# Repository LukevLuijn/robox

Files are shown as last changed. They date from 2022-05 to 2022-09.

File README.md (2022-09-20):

# ROBOX

Everything you need to build your own ROBOX!

## Documentation

|#|Document|Description|
|:---:|:---|:---|
|DOC-00|[**Message protocol**](https://github.com/LukevLuijn/robox_docs/blob/b1542c1bec19ce677cf1c12f30072f8e4e05e07a/protocol/protocol_description.pdf)|Description about the used protocol for the communication between the firmware and software.|
|DOC-01|[**Bill of materials**](https://github.com/LukevLuijn/robox_docs/blob/b1542c1bec19ce677cf1c12f30072f8e4e05e07a/hardware/bill_of_materials/README.md)|Bill of materials.|
|DOC-02|[**Design documentation**](https://github.com/LukevLuijn/robox_docs)|Full design documentation, all written in dutch.|

## Additional control methods

|#|Method|Description|State|
|:---:|:---|:---|:---|
|MD-01|[**BKE-Control**](https://github.com/LukevLuijn/robox/tree/BKE-control)|Models and code implementation for the ability to play games of noughts and crosses against human players autonomously.|Finished|
|MD-02|**BLT-Control**|Additional control method for controlling the robot trough a bluetooth controller such as a Playstation 4 controller.|Not started|
|MD-03|**Keyboard-control**|Additional control method for controlling the robot trough a combination of keys on a standard keyboard.|Not started|
|MD-04|**Vision-control**|Models and code implementation to control the robot trough a webcam and various visual triggers such as hand gestures or shapes.|Not started|

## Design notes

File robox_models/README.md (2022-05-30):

# ROBOX Models

This directory contains all .stl files needed to print your own ROBOX.

## Robox assembly

|||
|:--:|:---:|
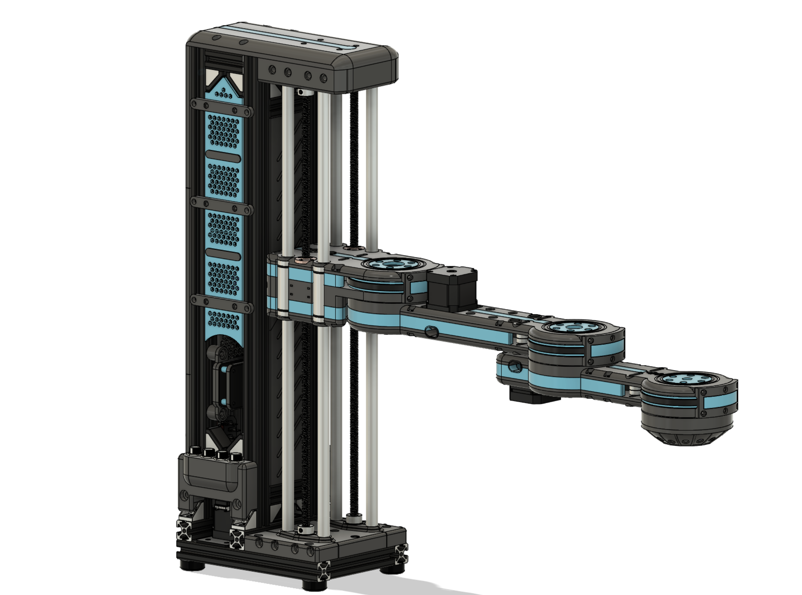
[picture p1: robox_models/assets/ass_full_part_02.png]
assembly01
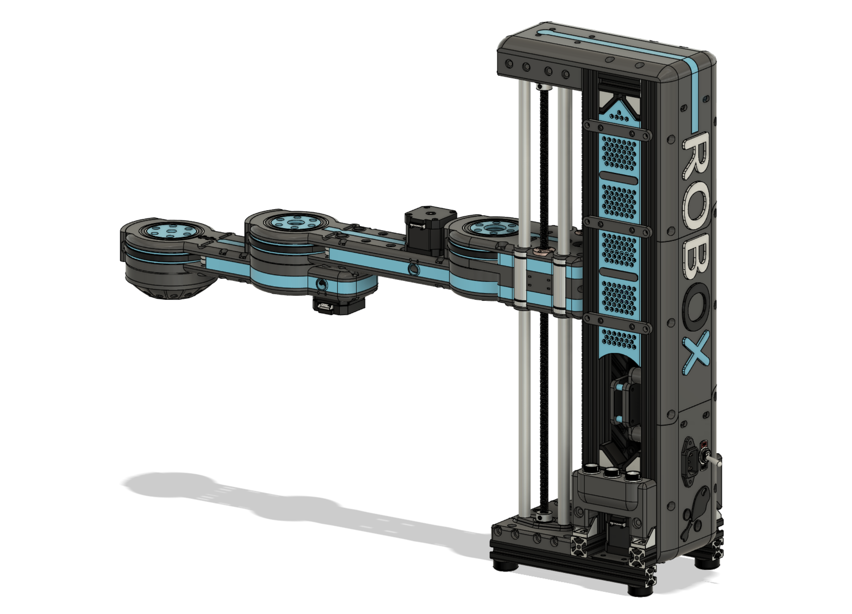
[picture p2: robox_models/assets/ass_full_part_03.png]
assembly02
|||
|**Image 1** - *Assembly front view*|**Image 2** - *Assembly back view*|

## Segments

|||
|:---:|:---:|
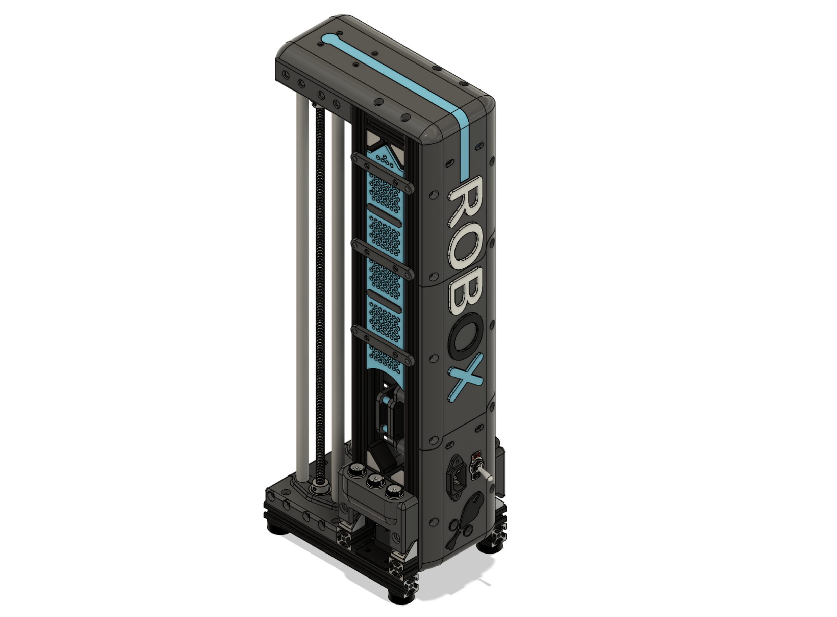
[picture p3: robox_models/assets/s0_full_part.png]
robox_segment_00
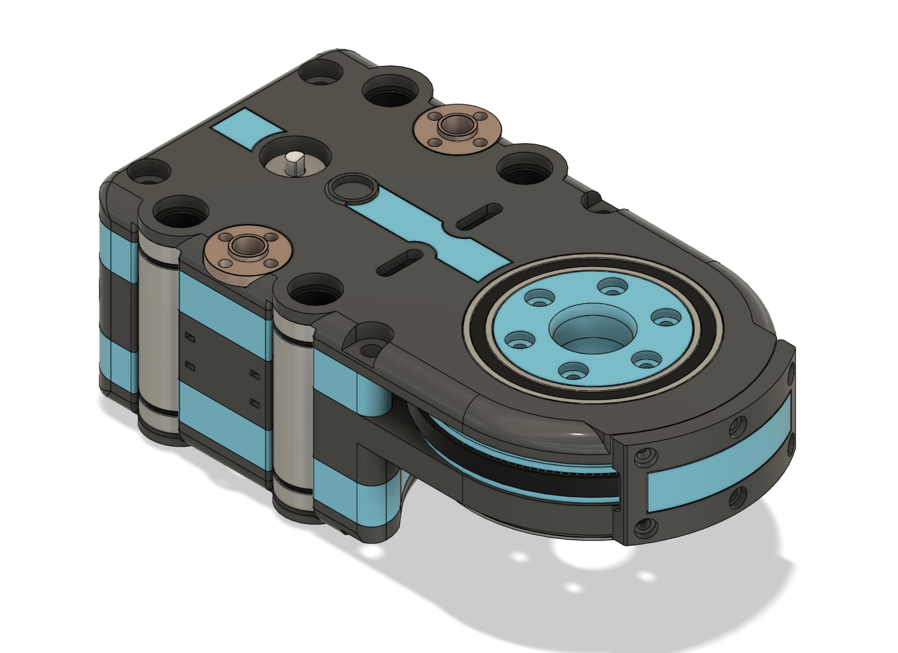
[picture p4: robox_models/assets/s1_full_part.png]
robox_segment_01
|||
|**Image 3** - *Segment 00*|**Image 4** - *Segment 01*|
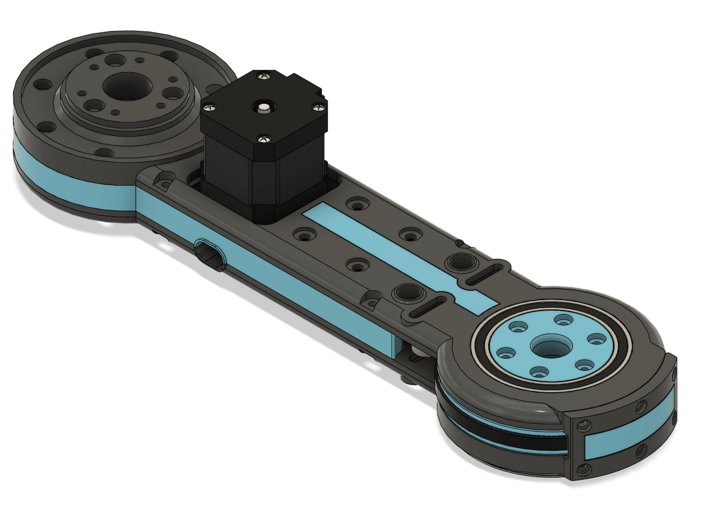
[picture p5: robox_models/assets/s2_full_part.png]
robox_segment_02
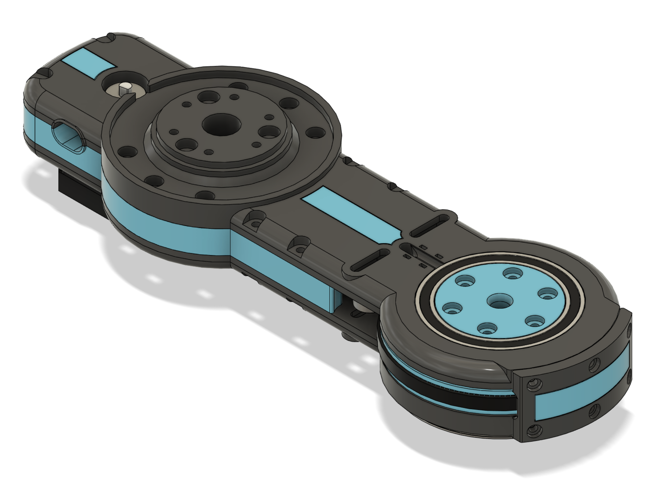
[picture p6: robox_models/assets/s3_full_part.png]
robox_segment_03
|||
|**Image 5** - *Segment 02*|**Image 6** - *Segment 03*|

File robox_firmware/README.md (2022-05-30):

# Robox firmware

This page contains the firmware for the ROBOX project. The firmware is produced to be run on a Teensy 4.0, it uses no external libraries.

## Wiring diagram

||
|:---:|
||
| **Image 1** - *Schematic*|

## Class diagrams

||
|:---:|
||
| **Diagram 1** - *Design class diagram*|
||
| **Diagram 2** - *Package Base*|
||
| **Diagram 3** - *Package Communication*|
||
| **Diagram 4** - *Package Device*|
||
| **Diagram 5** - *Package StateMachine*|
||
| **Diagram 6** - *Package Utils*|

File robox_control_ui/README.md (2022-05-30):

# Robox application

This page contains the software application for the ROBOX project. The software application uses the libraries wxWidgets & boost.

## Installation instructions

```bash
# From the root of the project folder.

$ mkdir build
$ cd build
$ cmake ..
$ make
$ ./robox
```

## Class diagrams

||
|:---:|
||
| **Diagram 1** - *Design class diagram*|
||
| **Diagram 1** - *Package Base*|
||
| **Diagram 1** - *Package Driver*|
||
| **Diagram 1** - *Package Frame*|
||
| **Diagram 1** - *Package Logger*|
||
| **Diagram 1** - *Package Utils*|
||
| **Diagram 1** - *Package Widgets*|

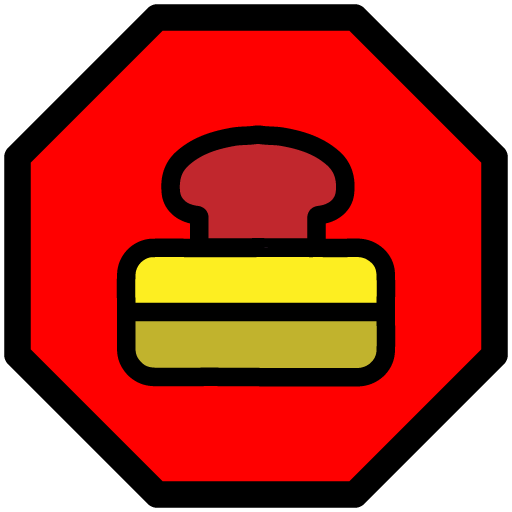
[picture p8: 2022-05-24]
robox_control_ui/assets/png/estop.png

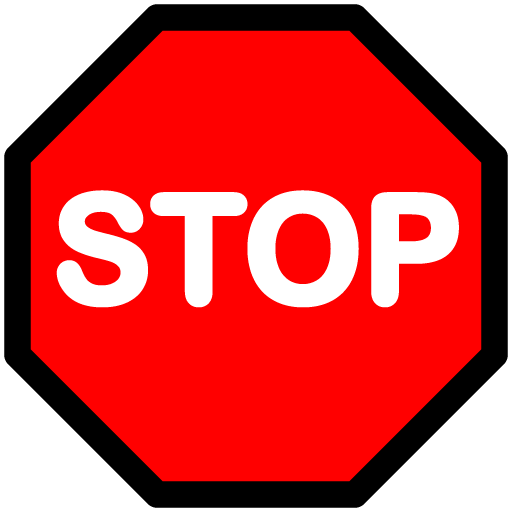
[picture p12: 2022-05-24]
robox_control_ui/assets/png/stop.png

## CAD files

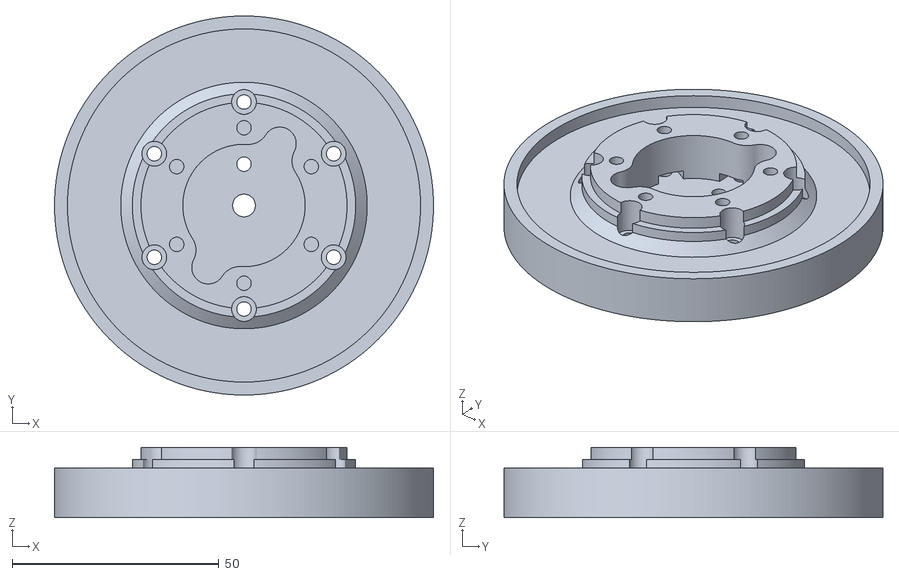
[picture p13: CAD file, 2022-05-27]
robox_models/gripper/connector.stl
91.7 x 91.7 x 17.0

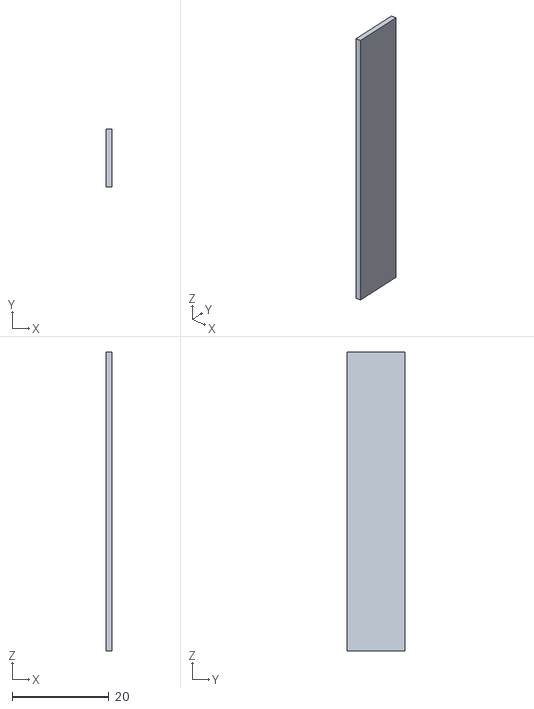
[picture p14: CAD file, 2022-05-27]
robox_models/segment_00/accent_pieces/00 (2).stl
1.20 x 11.9 x 61.8

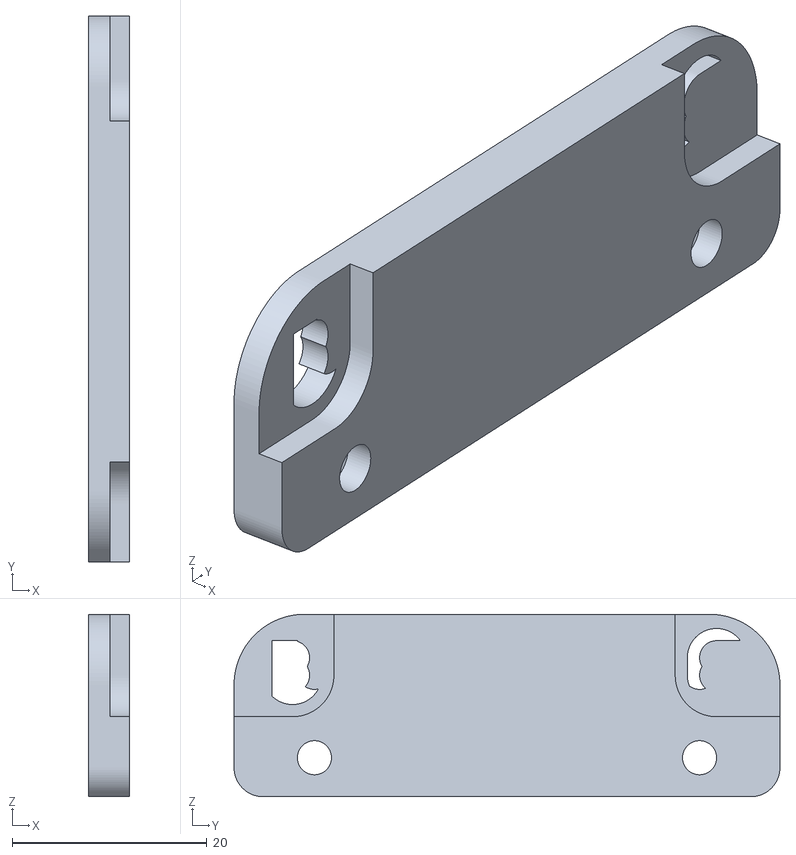
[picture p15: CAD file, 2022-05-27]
robox_models/segment_00/electronics_housing/psu_correction_bracket.stl
4.20 x 56.0 x 18.7

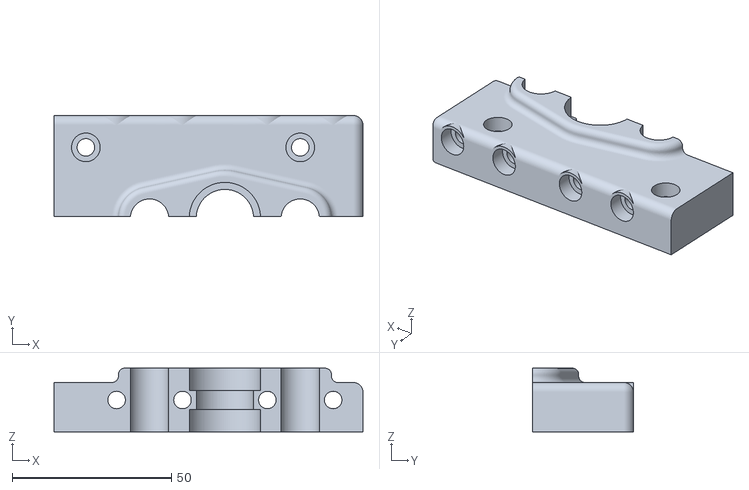
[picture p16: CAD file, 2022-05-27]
robox_models/segment_00/linear_motion/bot_holder_left.stl
97.0 x 31.7 x 20.0

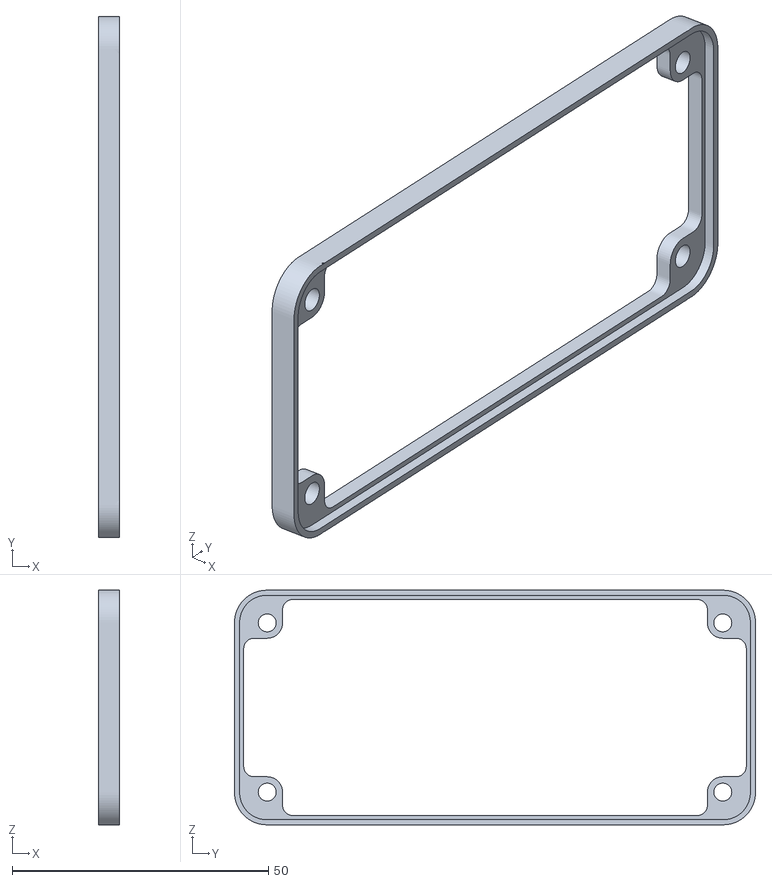
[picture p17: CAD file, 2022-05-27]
robox_models/segment_00/main_controller/motor_controller_top.stl
4.10 x 101.7 x 45.8

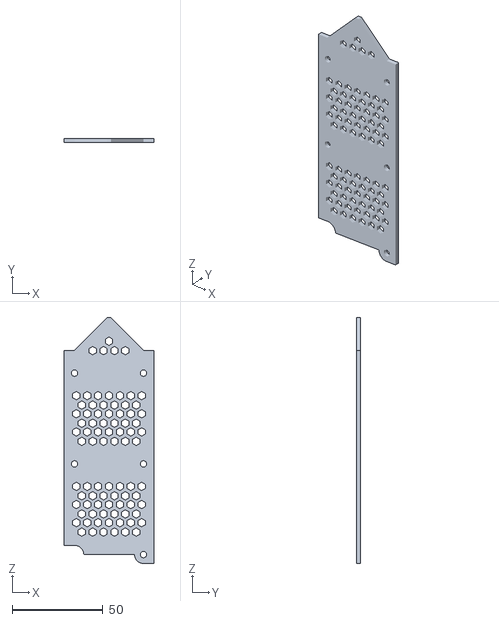
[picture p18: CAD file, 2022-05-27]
robox_models/segment_00/outer_panels/panel_top.stl
49.6 x 2.40 x 135.6

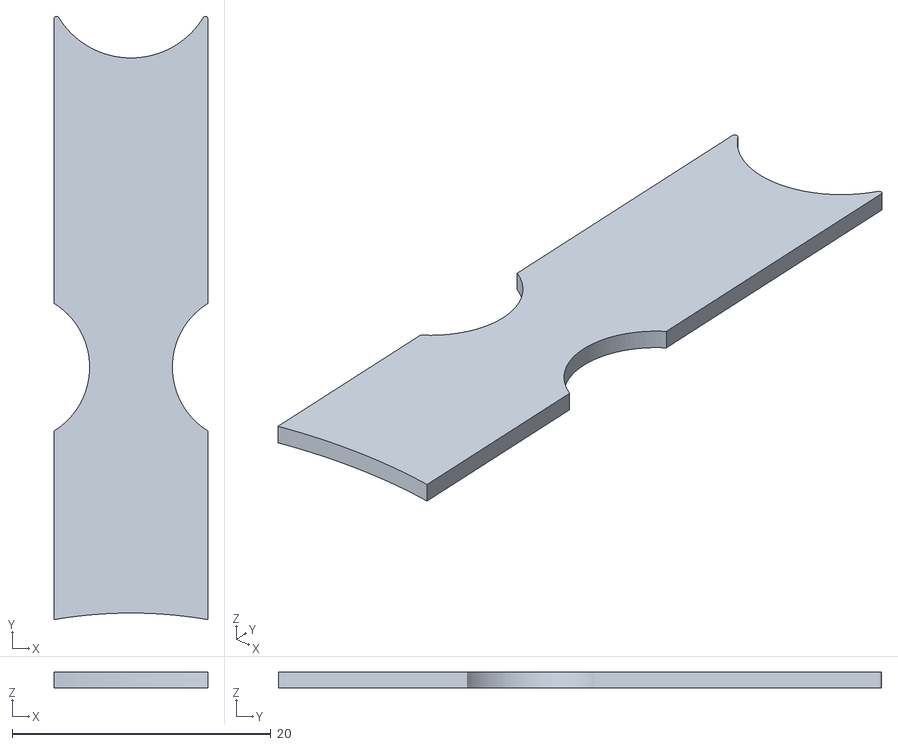
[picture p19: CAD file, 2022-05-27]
robox_models/segment_01/accent_pieces/01 (1).stl
11.9 x 46.6 x 1.20

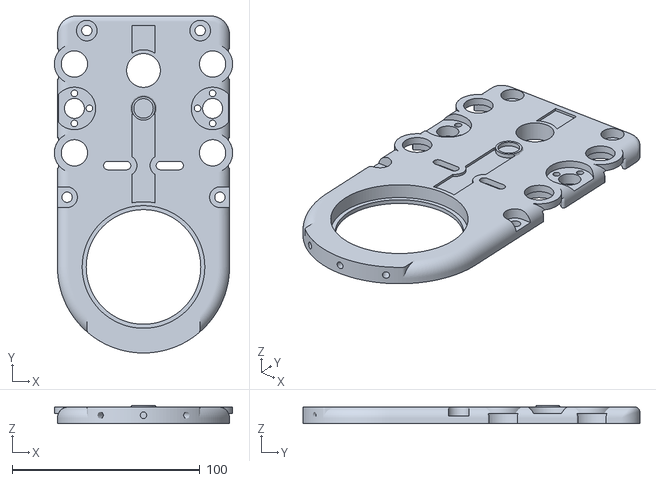
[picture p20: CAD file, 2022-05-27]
robox_models/segment_01/main_part/body_top.stl
95.0 x 179.5 x 9.80

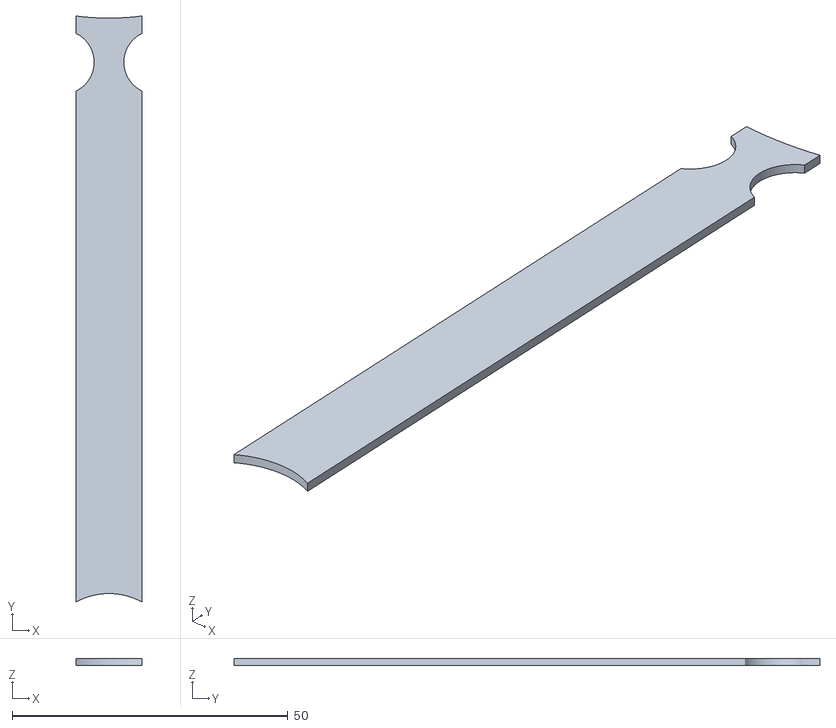
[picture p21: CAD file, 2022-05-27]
robox_models/segment_02/accent_pieces/02 (1).stl
11.9 x 106.3 x 1.20

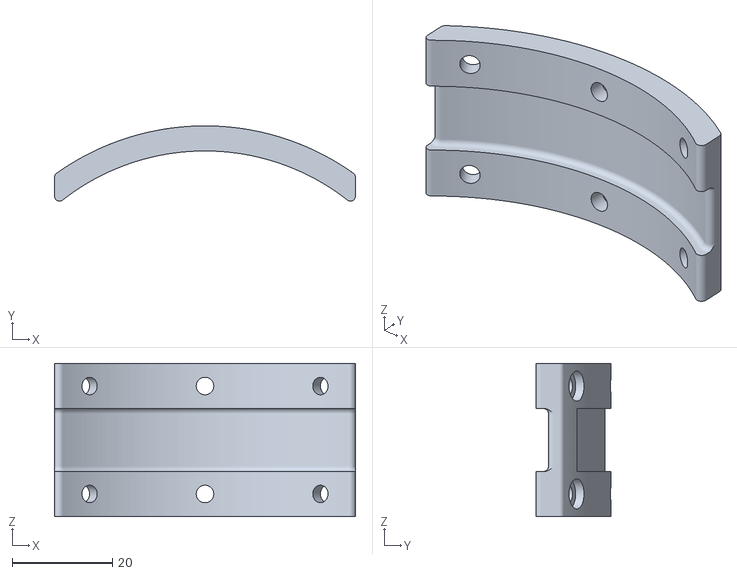
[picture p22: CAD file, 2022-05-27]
robox_models/segment_02/main_part/bumper_front.stl
60.0 x 15.0 x 30.5

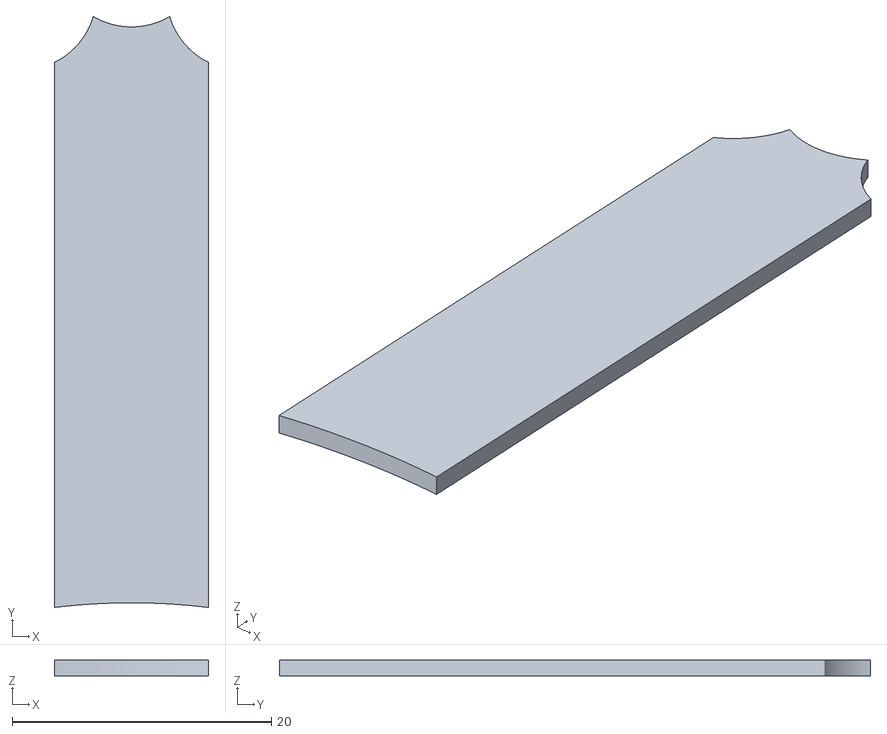
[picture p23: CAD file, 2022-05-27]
robox_models/segment_03/accent_pieces/03 (3).stl
11.9 x 45.6 x 1.20

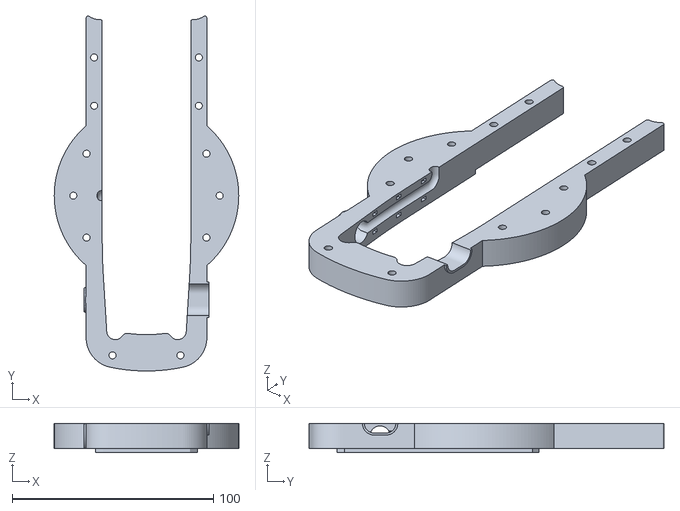
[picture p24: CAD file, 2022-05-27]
robox_models/segment_03/main_part/body_mid.stl
91.7 x 176.4 x 14.5

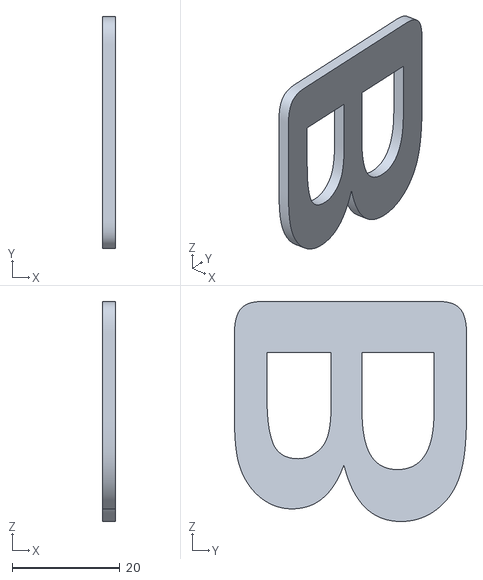
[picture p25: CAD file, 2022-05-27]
robox_models/segment_00/accent_pieces/title_B.stl
2.40 x 43.0 x 40.8

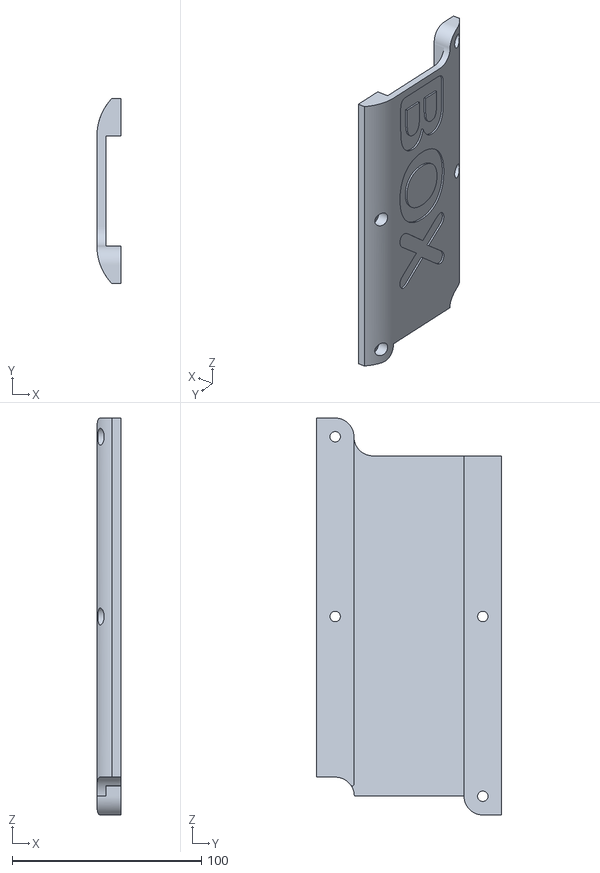
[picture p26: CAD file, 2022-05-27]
robox_models/segment_00/electronics_housing/back_cover_02.stl
12.8 x 98.0 x 209.8

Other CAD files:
robox_models/segment_00/linear_motion/pulley_spacer.stl
robox_models/segment_00/main_controller/frame_pcb_spacer.stl
robox_models/segment_00/outer_panels/panel_sub_bracket.stl
robox_models/segment_01/accent_pieces/01 (3).stl
robox_models/gripper/magnet_bracket.stl
robox_models/gripper/nut_holder.stl
robox_models/segment_00/accent_pieces/00 (0).stl
robox_models/segment_00/accent_pieces/00 (1).stl
robox_models/segment_00/accent_pieces/logo_bone.stl
robox_models/segment_00/accent_pieces/title_R.stl
robox_models/segment_00/accent_pieces/title_X.stl
robox_models/segment_00/electronics_housing/back_cover_01.stl
robox_models/segment_00/electronics_housing/back_cover_03.stl
robox_models/segment_00/electronics_housing/buck_converter_bracket.stl
robox_models/segment_00/electronics_housing/motor_connector_bracket.stl
robox_models/segment_00/electronics_housing/psu_correction_bracket (1).stl
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

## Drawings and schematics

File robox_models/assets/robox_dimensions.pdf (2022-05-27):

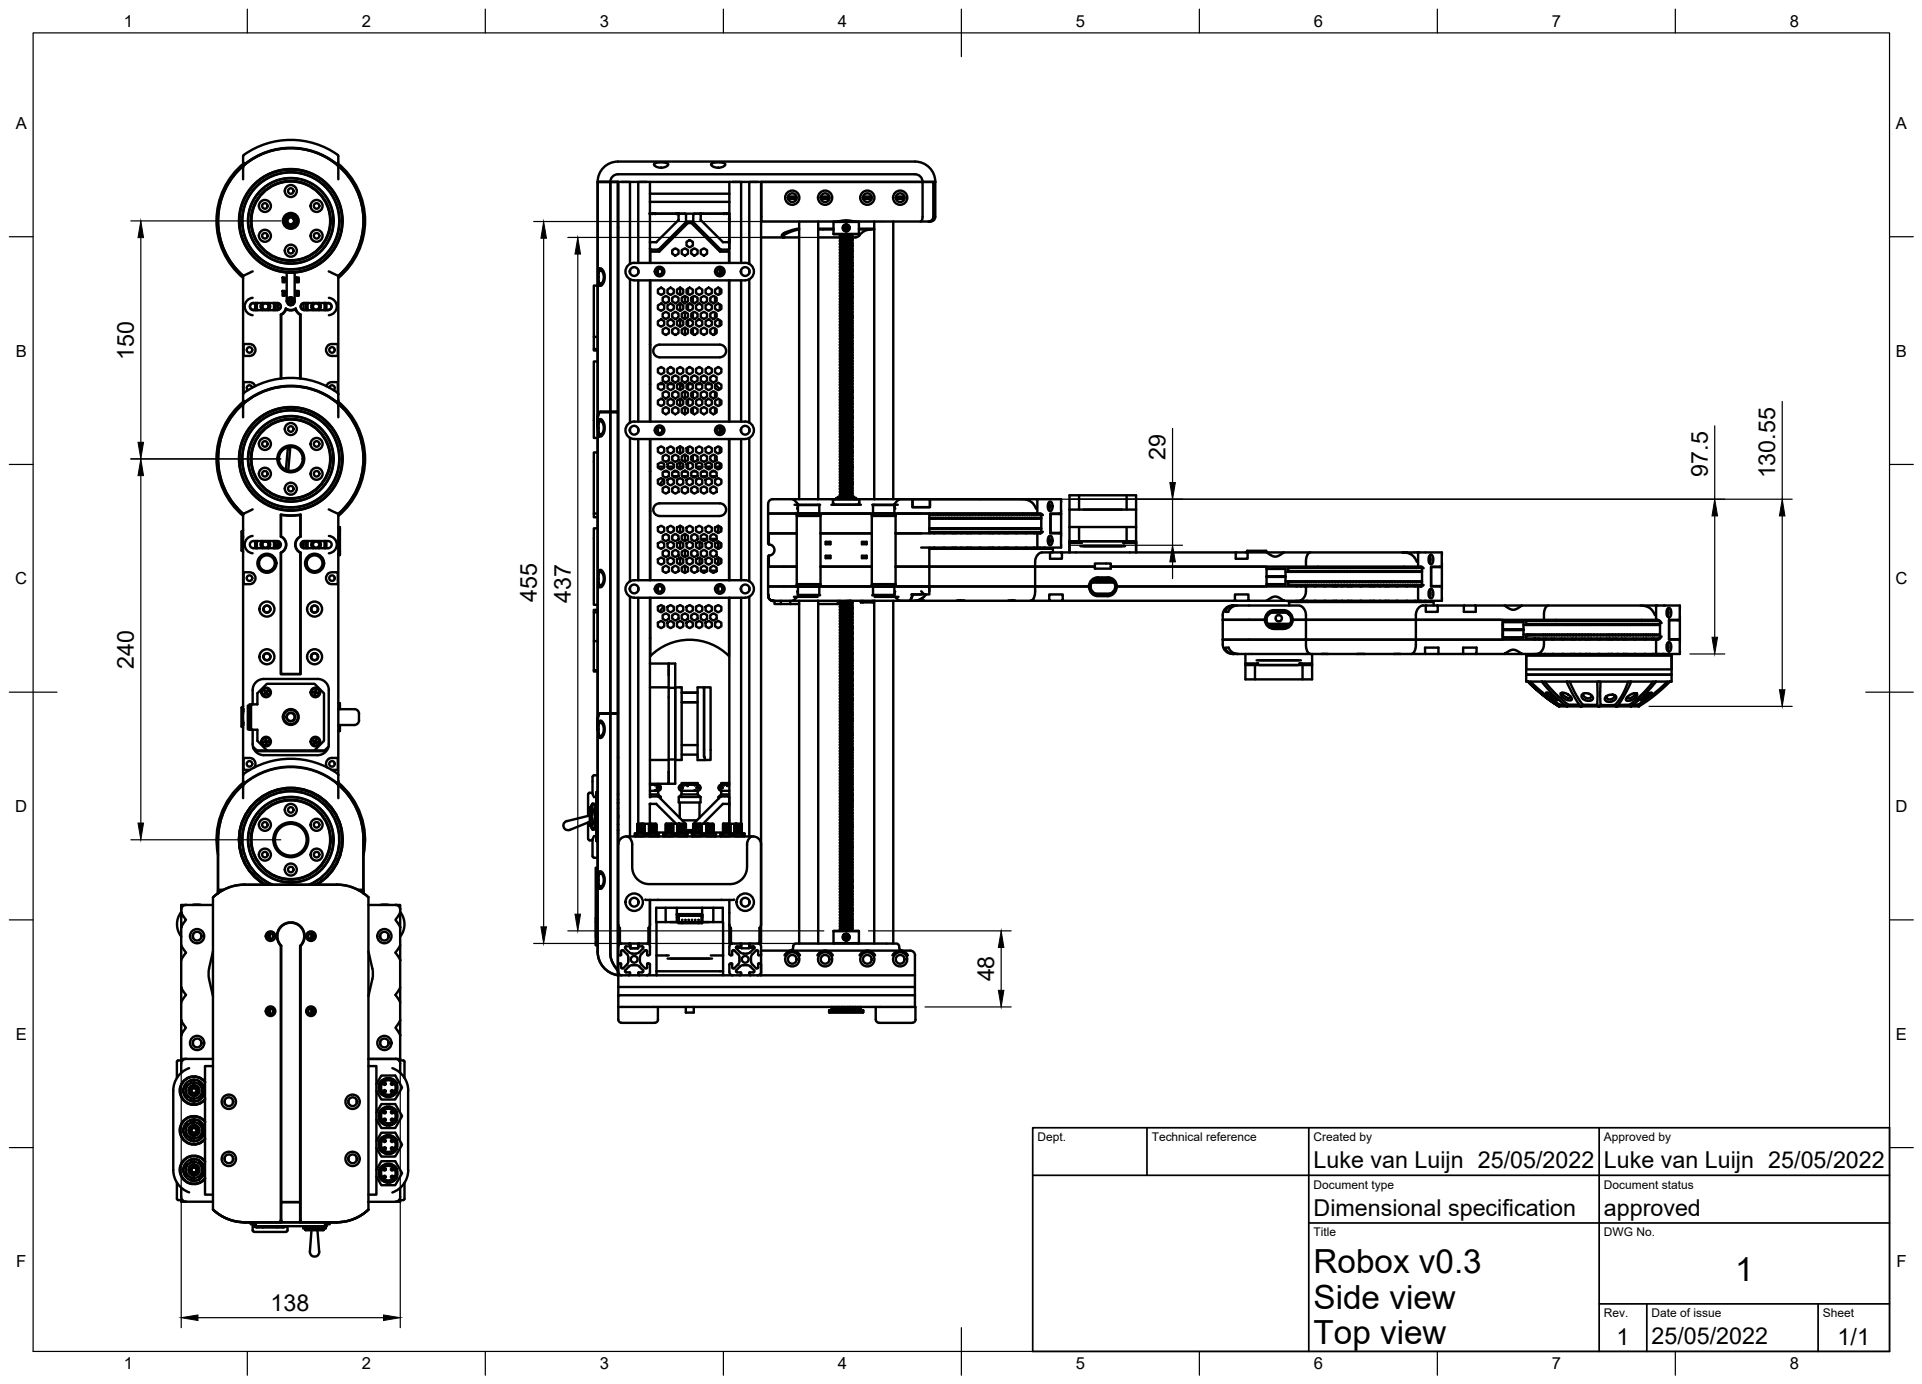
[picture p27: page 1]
Dept.; Technical reference; Created by; Approved by; Document type; Document status; Title; DWG No.; Rev.; Date of issue; Sheet; Top view; Dimensional specification; approved; Side view; Robox v0.3; Luke van Luijn; Luke van Luijn 240 150

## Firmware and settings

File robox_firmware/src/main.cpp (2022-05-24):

// ======================================
// Filename:    main.cpp
// Project:     ROBOX Motor controller
// Author:      Luke van Luijn
// Data:        14-05-2022
// ======================================

#include <Arduino.h>

#include "base/Machine.h"
#include "utils/Logger.h"

Base::Machine machine;

void setup()
{
    Serial.begin(9600);
    delay(1000);

    INFO("Hello world!");

    machine.Start();
}

void loop()
{
    machine.Run();
}

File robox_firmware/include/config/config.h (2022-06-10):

// ======================================
// Filename:    config.h
// Project:     ROBOX Motor controller
// Author:      Luke van Luijn
// Data:        14-05-2022
// ======================================

#ifndef ROBOX_CONTROLLER_CONFIG_H
#define ROBOX_CONTROLLER_CONFIG_H

// ROBOT HARDWARE CONFIGURATION

#define AMOUNT_OF_AXES 4

#define DEFAULT_STEPS_PER_REVOLUTION 200
#define DRIVER_MIN_PULSE_WIDTH 5

#define LENGTH_SEGMENT_01 240.0f
#define LENGTH_SEGMENT_02 150.0f

#define LEADSCREW_PITCH 8.0f

#define MAX_HEIGHT_SEGMENT_00 365.0f
#define MIN_HEIGHT_SEGMENT_00 0.0f
#define MAX_SPEED_SEGMENT_00 15000.0f
#define MAX_ACCEL_SEGMENT_00 15000.0f

#define MAX_ANGLE_SEGMENT_01 90.0f
#define MIN_ANGLE_SEGMENT_01 -90.0f
#define MAX_SPEED_SEGMENT_01 4250.0f//12000.0f
#define MAX_ACCEL_SEGMENT_01 4250.0f//12000.0f

#define MAX_ANGLE_SEGMENT_02 360.0f
#define MIN_ANGLE_SEGMENT_02 -360.0f
#define MAX_SPEED_SEGMENT_02 4250.0f//15000.0f
#define MAX_ACCEL_SEGMENT_02 4250.0f//15000.0f

#define MAX_ANGLE_SEGMENT_03 360.0f
#define MIN_ANGLE_SEGMENT_03 -360.0f
#define MAX_SPEED_SEGMENT_03 4250.0f
#define MAX_ACCEL_SEGMENT_03 4250.0f

#define HOMING_SPEED_SEGMENT_00 2750.0f//2750.0f
#define HOMING_ACCEL_SEGMENT_00 2750.0f//2750.0f

#define HOMING_SPEED_SEGMENT_01 4250.0f//4250.0f
#define HOMING_ACCEL_SEGMENT_01 4250.0f//4250.0f

#define HOMING_SPEED_SEGMENT_02 4250.0f
#define HOMING_ACCEL_SEGMENT_02 4250.0f

#define HOMING_SPEED_SEGMENT_03 4250.0f
#define HOMING_ACCEL_SEGMENT_03 4250.0f

// MOTOR PIN CONNECTIONS

#define MOTOR_STP_0 16//15
#define MOTOR_DIR_0 15//16
#define MOTOR_ENB_0 17//14

#define MOTOR_STP_1 5
#define MOTOR_DIR_1 6
#define MOTOR_ENB_1 4

#define MOTOR_STP_2 3//2
#define MOTOR_DIR_2 2//3
#define MOTOR_ENB_2 23

#define MOTOR_STP_3 8
#define MOTOR_DIR_3 7//9
#define MOTOR_ENB_3 9//7

// HALL SENSORS PIN CONNECTIONS

#define HALL_SENSOR_0 18// lift
#define HALL_SENSOR_2 20// seg 1
#define HALL_SENSOR_3 19// seg 2
#define HALL_SENSOR_1 21// gripper

// GRIPPER SIGNAL PINS

#define GRIPPER_SIGNAL_00 0
#define GRIPPER_SIGNAL_01 1

// SERIAL COMMUNICATION

#define BAUDRATE 9600
#define MESSAGE_SIZE 255

#define MESSAGE_START_CHAR '<'
#define MESSAGE_STOP_CHAR '>'

#define RESPONSE_START_CHAR '#'
#define RESPONSE_STOP_CHAR '*'

#define LOG_START_CHAR '@'
#define LOG_STOP_CHAR '*'

// SERIAL LOGGER CONFIGURATION

#define VERBOSITY_LEVELS 4

#define LOG_ERROR true
#define LOG_WARNING true
#define LOG_INFO true
#define LOG_DEBUG false

// HARDWARE OFFSETS

extern float FRAME_HEIGHT_OFFSET;
extern float GRIPPER_HEIGHT_OFFSET;
extern float IDLE_POS_SEGMENT_00;
extern float IDLE_POS_SEGMENT_01;
extern float IDLE_POS_SEGMENT_02;
extern float IDLE_POS_SEGMENT_03;
extern float ACTUAL_ZERO_POS_SEG_00;

#endif// ROBOX_CONTROLLER_CONFIG_H

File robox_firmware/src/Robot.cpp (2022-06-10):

// ======================================
// Filename:    Robot.cpp
// Project:     ROBOX Motor controller
// Author:      Luke van Luijn
// Data:        14-05-2022
// ======================================

#include "base/Robot.h"
#include "utils/Logger.h"

namespace Base
{
    Robot::Robot()
        : Z0(Device::LinearActuator(MOTOR_STP_0, MOTOR_DIR_0, MOTOR_ENB_0, HALL_SENSOR_0,
                                    Device::Microstepping_e::MS3200, 1.0f, false)),
          A1(Device::AxialActuator(MOTOR_STP_1, MOTOR_DIR_1, MOTOR_ENB_1, HALL_SENSOR_1,
                                   Device::Microstepping_e::MS3200, 7.2f, true, Device::HomingStyle_e::DOUBLE_MAGNET)),
          A2(Device::AxialActuator(MOTOR_STP_2, MOTOR_DIR_2, MOTOR_ENB_2, HALL_SENSOR_2,
                                   Device::Microstepping_e::MS3200, 7.2f, false, Device::HomingStyle_e::SINGLE_MAGNET)),
          A3(Device::AxialActuator(MOTOR_STP_3, MOTOR_DIR_3, MOTOR_ENB_3, HALL_SENSOR_3,
                                   Device::Microstepping_e::MS3200, 7.2f, false, Device::HomingStyle_e::SINGLE_MAGNET))
    {
    }
    void Robot::Start()
    {
        Z0.Start();
        DEBUG("Setup complete", "Linear actuator A0");

        A1.Start();
        DEBUG("Setup complete", "Linear actuator A0");

        A2.Start();
        DEBUG("Setup complete", "Linear actuator A0");

        A3.Start();
        DEBUG("Setup complete", "Linear actuator A0");

        DEBUG("Setup complete", "Robot");
    }
    void Robot::Run()
    {        
        Z0.Run();
        A1.Run();
        A2.Run();
        A3.Run();
    }
    void Robot::SetTarget(const Position& target)
    {
        SetTarget(Translate(target));
    }
    void Robot::SetTarget(const Angles& target)
    {
        if (CheckBounds(target))
        {
            Z0.MoveToHeight(target.Z0);
            A1.MoveToAngle(target.A1);
            A2.MoveToAngle(target.A2);
            A3.MoveToAngle(target.A3);


            String targetZ0 = "0:" + String(target.Z0);
            String targetA1 = "1:" + String(target.A1);
            String targetA2 = "2:" + String(target.A2);
            String targetA3 = "3:" + String(target.A3);
            String varString = targetZ0 + "," + targetA1 + "," + targetA2 + "," + targetA3;
            INFO("New target set", varString);
        }
    }
    void Robot::DisableRobot()
    {
        Z0.disableOutputs();
        A1.disableOutputs();
        A2.disableOutputs();
        A3.disableOutputs();

        INFO("Robot disabled");
    }
    void Robot::DisableJoint(Joint_e joint)
    {
        switch (joint)
        {
            case Joint_e::Z0:
                Z0.disableOutputs();
                break;
            case Joint_e::A1:
                A1.disableOutputs();
                break;
            case Joint_e::A2:
                A2.disableOutputs();
                break;
            case Joint_e::A3:
                A3.disableOutputs();
                break;
        }
        INFO("Joint disabled", String((uint16_t) joint));
    }
    void Robot::EnableRobot()
    {
        Z0.enableOutputs();
        A1.enableOutputs();
        A2.enableOutputs();
        A3.enableOutputs();

        INFO("Robot enabled");
    }
    void Robot::EnableJoint(Joint_e joint)
    {
        switch (joint)
        {
            case Joint_e::Z0:
                Z0.enableOutputs();
                break;
            case Joint_e::A1:
                A1.enableOutputs();
                break;
            case Joint_e::A2:
                A2.enableOutputs();
                break;
            case Joint_e::A3:
                A3.enableOutputs();
                break;
        }
        INFO("Joint enabled", String((uint16_t) joint));
    }
    void Robot::HomingSequence()
    {
        Z0.HomingSequence(HOMING_SPEED_SEGMENT_00, HOMING_ACCEL_SEGMENT_00, MAX_SPEED_SEGMENT_00, MAX_ACCEL_SEGMENT_00);
        A1.HomingSequence(HOMING_SPEED_SEGMENT_01, HOMING_ACCEL_SEGMENT_01, MAX_SPEED_SEGMENT_01, MAX_ACCEL_SEGMENT_01);
        A2.HomingSequence(HOMING_SPEED_SEGMENT_02, HOMING_ACCEL_SEGMENT_02, MAX_SPEED_SEGMENT_02, MAX_ACCEL_SEGMENT_02);
        A3.HomingSequence(HOMING_SPEED_SEGMENT_03, HOMING_ACCEL_SEGMENT_03, MAX_SPEED_SEGMENT_03, MAX_ACCEL_SEGMENT_03);
    }
    void Robot::ResetHoming()
    {
        Z0.ResetHoming();
        A1.ResetHoming();
        A2.ResetHoming();
        A3.ResetHoming();
        DEBUG("Homing sequence reset");
    }
    void Robot::SetGripperPWMSignal00(uint8_t signal)
    {
        m_valueGripper00 = signal;
        analogWrite(GRIPPER_SIGNAL_00, m_valueGripper00);

        DEBUG("PWM value set Gripper 00", String((uint16_t) signal));
    }
    void Robot::SetGripperPWMSignal01(uint8_t signal)
    {
        m_valueGripper01 = signal;
        analogWrite(GRIPPER_SIGNAL_01, m_valueGripper01);
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

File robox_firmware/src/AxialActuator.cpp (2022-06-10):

// ======================================
// Filename:    AxialActuator.cpp
// Project:     ROBOX Motor controller
// Author:      Luke van Luijn
// Data:        14-05-2022
// ======================================

#include "device/AxialActuator.h"
#include "utils/Time.h"
#include "utils/Logger.h"

namespace Device
{
    AxialActuator::AxialActuator(uint8_t stp, uint8_t dir, uint8_t enb, uint8_t limit, Microstepping_e microstepping,
                                 float reduction, bool inverted, HomingStyle_e style)
        : Actuator(stp, dir, enb, microstepping, reduction, inverted), m_stepsPerDegree(360.0 / m_stepsPerRevolution),
          m_limitPin(limit), m_switch(Device::HallSensor(limit)), m_homingStyle(style),
          m_homingStateDouble(HomingStateDouble_e::SETUP), m_homingStateSingle(HomingStateSingle_e::SETUP),
          m_homingTimer(0), m_homingIndex(0), m_magnetPos01(0), m_magnetPos02(0)
    {
    }
    void AxialActuator::MoveDegrees(float degrees)
    {
        float steps = degrees / m_stepsPerDegree;
        move(steps);
    }
    void AxialActuator::RunDegrees(float degrees)
    {
        float steps = degrees / m_stepsPerDegree;
        runToNewPosition(currentPosition() + steps);
    }
    void AxialActuator::MoveToAngle(float angle)
    {
        float steps = angle / m_stepsPerDegree;
        moveTo(steps);
    }
    void AxialActuator::RunToAngle(float angle)
    {
        float steps = angle / m_stepsPerDegree;
        runToNewPosition(currentPosition() + steps);
    }
    float AxialActuator::GetCurrentAngle()
    {
        float angle = currentPosition() * m_stepsPerDegree;        
        return angle;
    }
    float AxialActuator::GetDegreesToTarget()
    {
        return (float) distanceToGo() / m_stepsPerDegree;
    }
    void AxialActuator::HomingSequence(float homingSpeed, float homingAccel, float speed, float accel)
    {
        switch (m_homingStyle)
        {
            case HomingStyle_e::SINGLE_MAGNET:
                HomeSingleMagnet(homingSpeed, homingAccel, speed, accel);
                break;
            case HomingStyle_e::DOUBLE_MAGNET:
                HomeDoubleMagnet(homingSpeed, homingAccel, speed, accel);
                break;
        }
    }
    bool AxialActuator::HomingComplete()
    {
        return (m_homingStyle == HomingStyle_e::SINGLE_MAGNET)
                       ? m_homingStateSingle == HomingStateSingle_e::HOMING_COMPLETE
                       : m_homingStateDouble == HomingStateDouble_e::HOMING_COMPLETE;
    }
    void AxialActuator::ResetHoming()
    {
        m_homingStateSingle = HomingStateSingle_e::SETUP;
        m_homingStateDouble = HomingStateDouble_e::SETUP;
    }
    float AxialActuator::GetStepsPerDegree()
    {
        return m_stepsPerDegree;
    }
    void AxialActuator::HomeSingleMagnet(float homingSpeed, float homingAccel, float speed, float accel)
    {
        const uint32_t INTERVAL_FAST = 300, INTERVAL_SLOW = 300;

        switch (m_homingStateSingle)
        {
            case HomingStateSingle_e::SETUP:
            {
                m_homingIndex = 0;
                m_switch.Start();
                setMaxSpeed(homingSpeed);
                setAcceleration(homingAccel);

                m_homingStateSingle = HomingStateSingle_e::FIRST_PASS;
            }
            case HomingStateSingle_e::FIRST_PASS:
            {
                if (digitalRead(m_limitPin))
                {
                    setCurrentPosition(0);
                    setMaxSpeed(homingSpeed);
                    setAcceleration(homingAccel);
                    m_homingIndex = 1;
                    m_homingStateSingle = HomingStateSingle_e::SECOND_PASS;
                }
                else if (Utils::MicroTimer(m_homingTimer, INTERVAL_FAST))
                {
                    moveTo(m_homingIndex);
                    m_homingIndex--;
                    run();
                }
            }
            break;
            case HomingStateSingle_e::SECOND_PASS:
            {
                if (m_switch.Trigger())
                {
                    m_magnetPos01 = currentPosition();

                    setCurrentPosition(0);
                    setMaxSpeed(homingSpeed);
                    setAcceleration(homingAccel);
                    MoveDegrees(30.0f);
                    m_homingStateSingle = HomingStateSingle_e::MOVING_OFFSET;
                }
                else if (Utils::MicroTimer(m_homingTimer, INTERVAL_SLOW))
                {
                    moveTo(m_homingIndex);
                    m_homingIndex++;
                    run();
                }
            }
            break;
            case HomingStateSingle_e::MOVING_OFFSET:
            {
                if (distanceToGo() > 0)
                {
                    run();
                }
                else
                {
                    m_homingIndex = currentPosition();
                    m_homingStateSingle = HomingStateSingle_e::FOURTH_PASS;
                }
            }
            break;
            case HomingStateSingle_e::FOURTH_PASS:
            {
                if (m_switch.Trigger())
                {
                    m_magnetPos02 = currentPosition() + m_magnetPos01;

                    setCurrentPosition(0);
                    setMaxSpeed(homingSpeed);
                    setAcceleration(homingAccel);

                    float magnetDelta = m_magnetPos02 - m_magnetPos01;
                    float zeroPos = magnetDelta / 2;
                    zeroPos += (180.0f / m_stepsPerDegree);
                    move(-zeroPos);

                    m_homingStateSingle = HomingStateSingle_e::ZERO_POS_MOVE;
                }
                else if (Utils::MicroTimer(m_homingTimer, INTERVAL_SLOW))
                {
                    moveTo(m_homingIndex);
                    m_homingIndex--;
                    run();
                }
            }
            break;
            case HomingStateSingle_e::ZERO_POS_MOVE:
            {
                if (distanceToGo() != 0)
                {
                    run();
                }
                else
                {
                    stop();
                    setCurrentPosition(0);
                    setMaxSpeed(speed);
                    setAcceleration(accel);
                    moveTo(0);
                    m_homingStateSingle = HomingStateSingle_e::HOMING_COMPLETE;
                }
            }
            break;
            case HomingStateSingle_e::HOMING_COMPLETE:
            default:
                break;
        }
    }
    void AxialActuator::HomeDoubleMagnet(float homingSpeed, float homingAccel, float speed, float accel)
    {
        const uint32_t INTERVAL_FAST = 750, INTERVAL_SLOW = 2500;
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

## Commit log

2022-05-27 Added .stl files
    [00 (0).stl, 00 (1).stl, 00 (2).stl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]
2022-05-27 Fixed speed issue, speed increased with 654 percent
    [config.h]
2022-05-28 seperated homing speed with max speed for axial & linear joints. Upped speed A1:282%, A2 & A3:352%
